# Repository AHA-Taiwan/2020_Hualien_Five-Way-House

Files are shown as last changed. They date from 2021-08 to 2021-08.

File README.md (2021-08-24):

# 2020｜花蓮壽豐｜誠什商店
## _Five-Way House_, Hualien, Taiwan

>Humanitarian Architecture in Hualien<br/>
>
>以台灣國產木材為主體構築材料之人道建築案例，主要材料來源自：行政院農業委員會林務局「台灣木材」標章與明吉木業「台灣杉」。由GROUP B（國立臺南藝術⼤學建築藝術研究所場域。結構。⾏動組）發展設計，與大花蓮縣鄉村社區⼤學發展協會、五味屋學童及國立臺南藝術⼤學建築藝術研究所學校單位合作進行實作。<br/>

從豐⽥⾞站出發，沿途觀察豐裡社區、五味屋及其位於各地的據點，最後回到五味屋裡的孩⼦，都是值得被細細閱讀的⼈⽂與歷史。期望藉由此項計畫，結合在地美感教育，使來訪的⼈們了解豐裡社區，關懷在地⽂化。以「誠什商店」為起點，整合村⼦特⾊以及在地孩⼦們的⽇常⼯作樣貌，串聯整個豐裡社區：透過孩⼦與村⺠們的實際參與，制定專屬課程，從修繕到維護，從中學習結構美學、建立⽣活美感，進⼀步培養⾃⼒造屋的能⼒，也喚起對這塊⼟地的歸屬感，塑造豐裡社區獨特⽣活模樣。<br/>

## 基地環境：<br/>
台灣東南地區，北回歸線以南，有焚風、颱風、東北季風，海風具高度鹽分，設計時需注意材料防潮防蝕保護。<br/>
* 基地環境氣象資料：https://www.cwb.gov.tw/V8/C/W/Town/Town.html?TID=1001506 <br/>
* 氣象觀測歷史紀錄：<br/>
https://e-service.cwb.gov.tw/HistoryDataQuery/DayDataController.do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<br/>

* 花蓮縣縣氣候月平均氣溫、月平均降雨量、風速與相對濕度數據圖表<br/>
 （取自交通部中央氣象局，統計期間為 1991-2020 年）<br/>



* Google Map 位置：https://goo.gl/maps/mkiesZs2zZFcKfTb6<br/>


***
## 專案介紹：<br/>

* 主要建材：台灣杉 [ 15 x 32 x 120 cm ] 尺寸。
* 數位模型［ 整體木構 3D ］：

室內木構 Interior Post and Beam/Wooden Structures<br/>
Digital Model Link: https://skfb.ly/opw7H 與 https://skfb.ly/opw7W
<br/>
<br/>
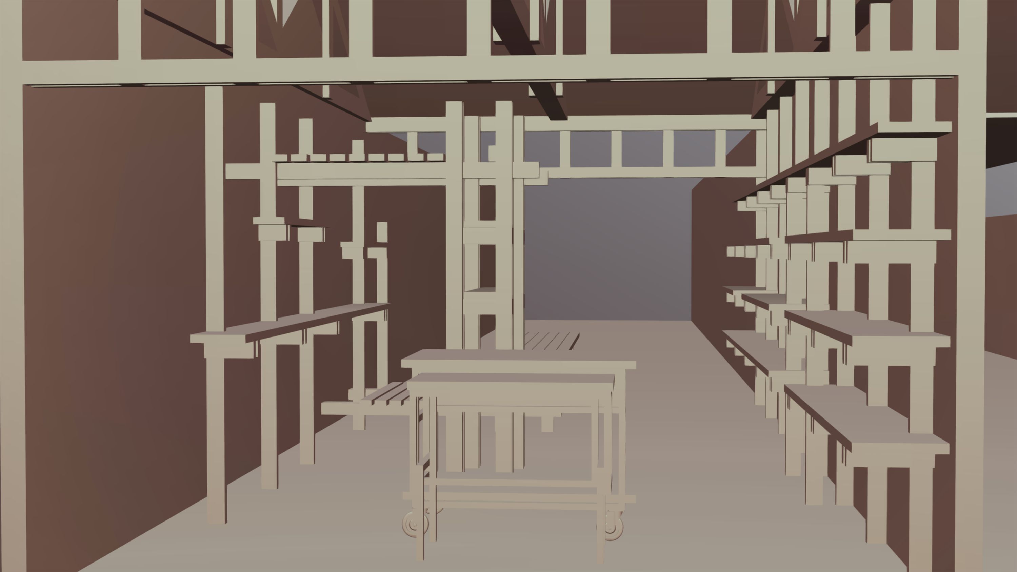
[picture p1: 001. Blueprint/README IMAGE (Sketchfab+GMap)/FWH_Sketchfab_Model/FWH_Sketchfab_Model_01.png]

<br/>
<br/>
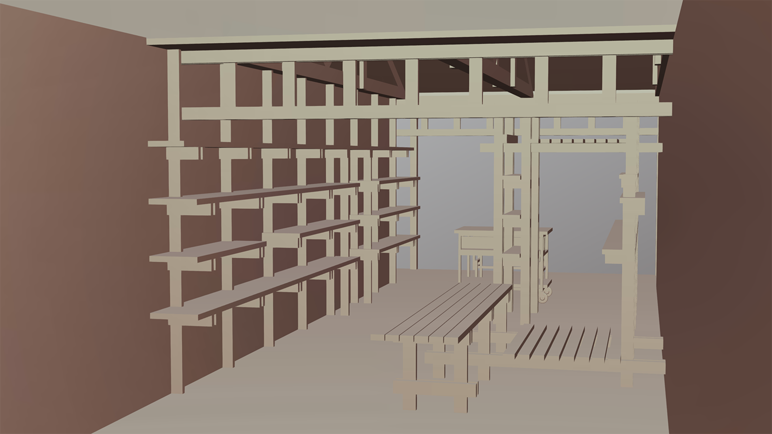
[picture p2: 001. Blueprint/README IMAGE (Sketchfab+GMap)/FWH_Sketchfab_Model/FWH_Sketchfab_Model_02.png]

<br/>
<br/>
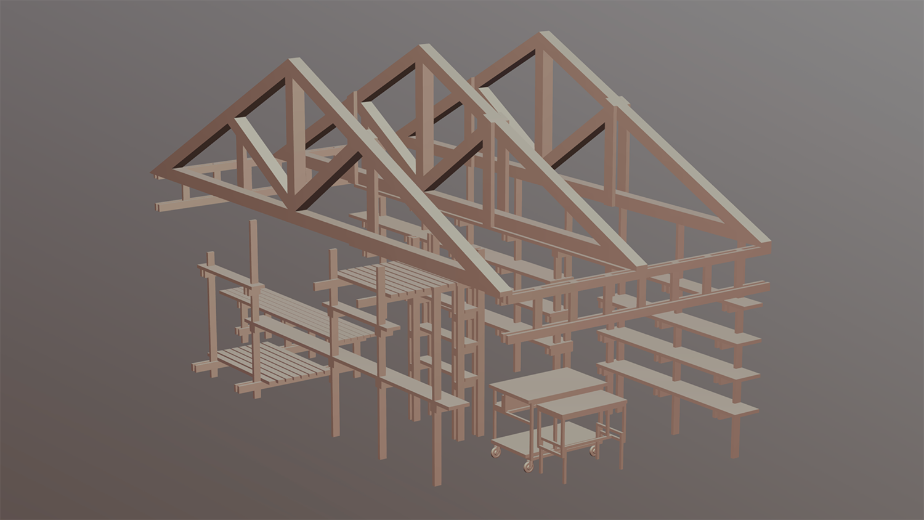
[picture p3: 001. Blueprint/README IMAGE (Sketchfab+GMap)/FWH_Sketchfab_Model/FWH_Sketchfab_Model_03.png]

<br/>
<br/>
推車木桌 Desk Trolley<br/>
Digital Model Link: https://skfb.ly/opwqn
<br/>
<br/>
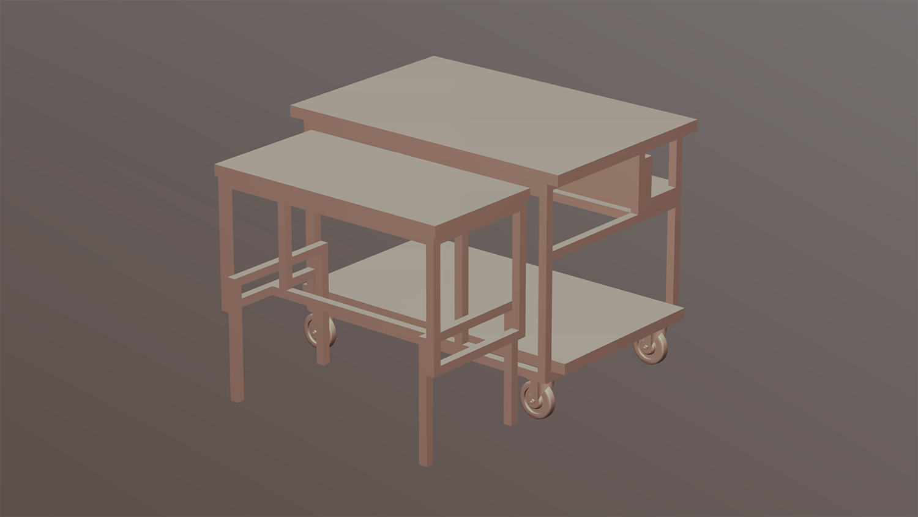
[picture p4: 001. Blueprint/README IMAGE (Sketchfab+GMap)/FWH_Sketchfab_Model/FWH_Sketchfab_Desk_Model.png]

<br/>
<br/>
***
## 如何達成合作建造：<br/>
* 請參閱［初次合作建造就上手 Collab-Const-Quick-Guide］：<br/>
https://github.com/AHA-Taiwan/Collab-Const-Quick-Guide/wiki <br/>
***
## 確保工作安全：<br/>
* 請參閱［合作建造-安全規範 Collab-Const-Safety］：<br/>
https://github.com/AHA-Taiwan/Collab-Const-Safety/wiki <br/>
***
## 探索合作資源：<br/>
* 請參閱［合作建造-資源探索 Collab-Const-Source］：<br/>
https://github.com/AHA-Taiwan/Collab-Const-Source/wiki <br/>
***
## 取得建造知識：<br/>
* 關於一般的常用構造技術（Techniques），請參閱［合作建造-學習知識 Collab-Const-Learning］：<br/>
https://github.com/AHA-Taiwan/Collab-Const-Learning/wiki <br/>
* 關於本案的特殊構築技術（Tectonic）， 請參閱［本案資料夾 002. Handbook］：<br/>
https://github.com/AHA-Taiwan/2020_Hualien_Five-Way-House/tree/main/002.%20Handbook<br/>
***

> #### 歡迎參與專案開發，Branch合併可向專案管理者提出請求

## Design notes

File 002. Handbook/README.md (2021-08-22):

Constr-Process Sheet (.doc+pdf)--工項工序表<br/>

Construction Method (photos)--施工工法, Link: https://drive.google.com/drive/u/4/folders/16N8T6Yqsu6y0wHSA50tWvrSBKL6h-Asd

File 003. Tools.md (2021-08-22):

# 工具清單與故障維修紀錄 
主要紀錄整體施工過程中，所有使用之工具名稱、規格、數量、單位、廠牌、工具來源、維修紀錄(日期)等，從中可間接推估工具數量及機具購買或租借成本。

## 安全工具 
|編碼|工具名稱|規格|數量|單位|廠牌|工具來源|維修紀錄|
|:-:|:-:|:-:|:-:|:-:|:-:|:-:|:-:|
|SS001|安全帽|工地用|6|頂|一般|AHA TL|無|
|SS002|安全繩|跳傘式|2|條|一般|AHA TL|無|
|SS003|安全繩|腰繫式|4|條|一般|AHA TL|無|
|SS004|護目罩|一般|6|副|一般|AHA TL|無|
|SS005|口罩|一般|1|盒|一般|AHA TL|無|
|SS006|手套|一般|4|打|一般|AHA TL|無|
|SS007|蚊帳|一般|4|頂|一般|AHA TL|無|
|SS008|工作板|一般|2|片|一般|AHATL|無|
***
## 手工具 
|編碼|工具名稱|規格|數量|單位|廠牌|工具來源|維修紀錄|
|:-:|:-:|:-:|:-:|:-:|:-:|:-:|:-:|
|HT001|捲尺|5.5m)|6|個|一般|AHA TL|無|
|HT002|大直角尺|一般|4|把|一般|AHA TL|無|
|HT003|小直角尺|一般|4|把|一般|AHA TL|無|
|HT004|大夾具|F夾|4|把|一般|AHA TL|無|
|HT005|小夾具|F夾|4|把|一般|AHA TL|無|
|HT006|老虎鉗|一般|5|把|一般|AHA TL|無|
|HT007|尖嘴鉗|一般|5|把|一般|AHA TL|無|
|HT008|螺絲起子|一般|5|把|一般|AHA TL|無|
|HT009|老鼠尾|一般|5|把|一般|AHA TL|無|
|HT010|大鐵鎚|一般|1|支|一般|AHA TL|無|
|HT011|鐵鎚|一般|6|支|一般|AHA TL|無|
|HT012|鐵鎚|一般|6|支|一般|AHA TL|無|
|HT013|板手|一般|10|支|一般|AHA TL|無|

***
## 電動工具 
|編碼|工具名稱|規格|數量|單位|廠牌|工具來源|維修紀錄|
|:-:|:-:|:-:|:-:|:-:|:-:|:-:|:-:|
|PT001|手持線鋸機|一般|2|台|一般|AHA TL|無|
|PT002|砂輪機|一般|2|台|一般|AHA TL|無|
|PT003|插電式電鑽|一般|4|支|一般|AHA TL|無|
|PT004|角度鋸|一般|1|台|一般|AHA TL|無|
|PT005|直立式鑽床|一般|1|台|一般|AHA TL|無|
***
## 氣動工具 
|編碼|工具名稱|規格|數量|單位|廠牌|工具來源|維修紀錄|
|:-:|:-:|:-:|:-:|:-:|:-:|:-:|:-:|
|AT001|空壓機|一般|1|台|士東|AHA TL|無|
|AT002|空壓機管|一般|1|條|士東|AHA TL|無|
|AT003|氣動拋光機|RC5|2|台|士東|AHA TL|無|
|AT004|轉接頭|三叉|1|個|一般|AHA TL|無|
|AT005|空氣噴槍|一般|1|支|一般|AHA TL|無|
***
## 輔助工具 
|編碼|工具名稱|規格|數量|單位|廠牌|工具來源|維修紀錄|
|:-:|:-:|:-:|:-:|:-:|:-:|:-:|:-:|
|FS001|動力延長線|100M|3|條|一般|AHA TL|無|
|FS002|輪座延長線|100M|1|座|一般|AHA TL|無|
|FS003|鹵素地燈|一般|2|座|一般|AHA TL|無|
|FS004|鹵素地燈管|一般|14|條|一般|AHA TL|無|
|FS005|LED 地燈|一般|3|座|一般|AHA TL|無|
|FS006|工作燈|一般|6|座|一般|AHA TL|無|
|FS007|工作燈泡|一般|10|顆|一般|AHA TL|無|
|FS008|頭燈|一般|2|條|一般|AHA TL|無|
|FS009|工作梯|一般|2|組|一般|AHA TL|無|
|FS010|腳架|一般|1|支|一般|AHA TL|無|
|FS011|籃子|一般|4|台|一般|AHA TL|無|
|FS012|墨綠色工作袋|一般|2|袋|一般|AHA TL|無|
***
## 耗材工具 
|編碼|工具名稱|規格|數量|單位|廠牌|工具來源|維修紀錄|
|:-:|:-:|:-:|:-:|:-:|:-:|:-:|:-:|
|TC001|墨斗+墨汁|無|1|組|一般|AHA TL|無|
|TC002|油漆刷|無|10|把|一般|AHA TL|無|
|TC003|鉛筆|無|10|支|一般|AHA TL|無|
|TC004|麥克筆|無|5|支|一般|AHA TL|無|
|TC005|圓形砂紙|一般|2|盒|一般|AHA TL|無|
|TC006|砂紙|#150|1|盒|一般|AHA TL|無|
|TC007|砂紙|#240|1|盒|一般|AHA TL|無|
|TC008|水線|一般|1|捆|一般|AHA TL|無|
|TC009|鋼釘|一般|1|盒|一般|AHA TL|無|
|TC010|切砂輪片|一般|10|片|一般|AHA TL|無|
|TC011|磨砂輪片|一般|5|片|一般|AHA TL|無|
|TC012|線鋸片紙盒|一般|1|盒|一般|AHA TL|無|
|TC013|長鑽頭|15mm|1|支|一般|AHA TL|無|
|TC014|長鑽頭|8mm|4|支|一般|AHA TL|無|
|TC015|鑽頭組白盒|一般|2|盒|一般|AHA TL|無|
|TC016|鑽頭組紙盒|一般|1|盒|一般|AHA TL|無|

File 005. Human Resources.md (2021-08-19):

# 專業者佈局與人力成本紀錄 
主要紀錄整體施工過程中，專業者、準專業者、非專業者於不同工項所花費時數，從中可間接推估建造施工人力經費及時間成本。
專業者M、準專業者P、非專業者N，當地人加註C

***
## 室內木構與推車木桌
|人力編碼|當地人|工作總時數(hrs)|請工|換工|志工|
|:-:|:-:|:-:|:-:|:-:|:-:|
|M01 | |80 | | |V |
|P01 | |80 | | |V |
|P02 | |80 | | |V |
|P03 | |80 | | |V |
|P04 | |80 | | |V |
|P05 | |80 | | |V |
|N01 | |80 | | |V |
|N02 | |80 | | |V |
|N03 | |80 | | |V |
|N04 | |80 | | |V |
|N05 | |80 | | |V |
|N06 | |80 | | |V |
|N07 | |80 | | |V |
|N08 | |80 | | |V |
|N09 | |80 | | |V |
***

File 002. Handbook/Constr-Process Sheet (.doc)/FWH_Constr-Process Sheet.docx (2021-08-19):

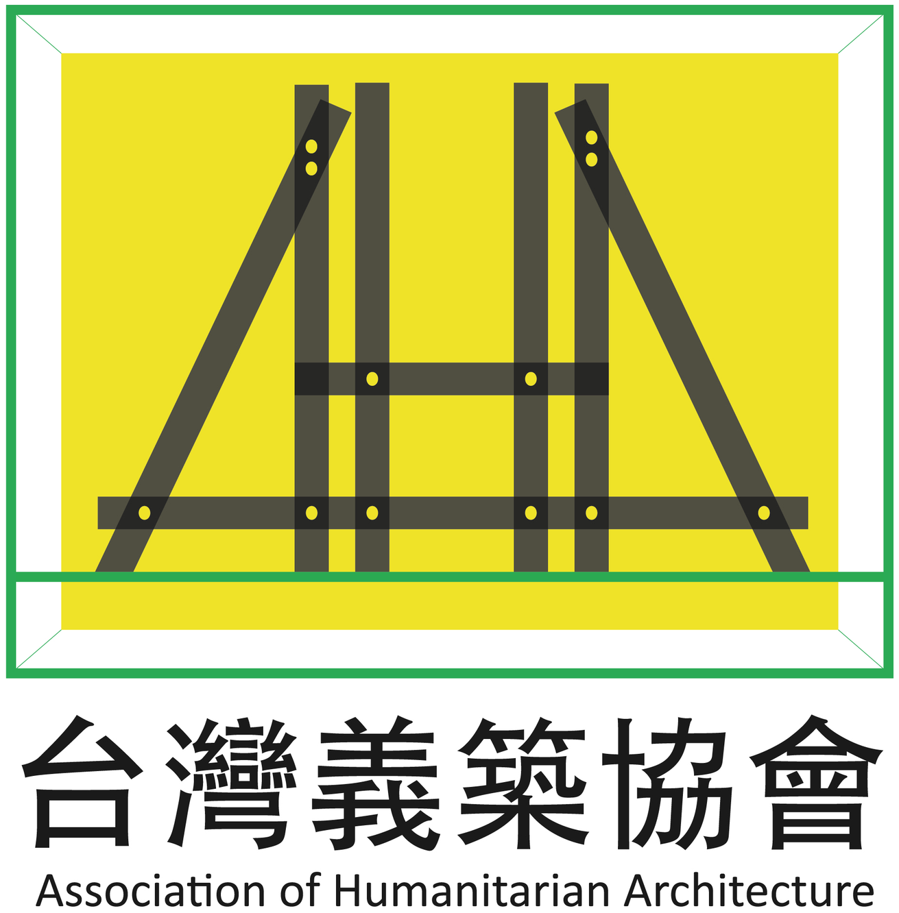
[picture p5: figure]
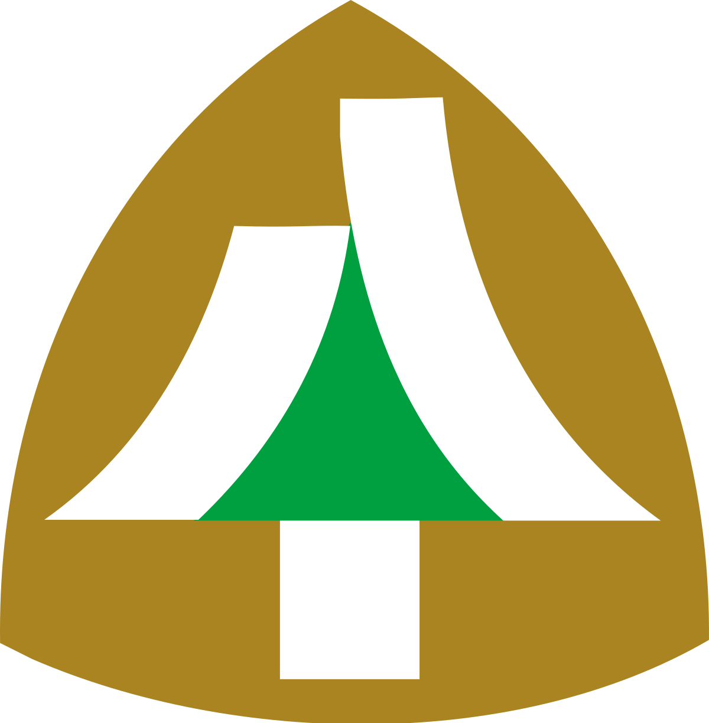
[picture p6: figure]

2020年 花蓮五味屋 誠什商店&誠什車 義築作品

生產製程文件

作業一、整理基地環境 | | 項次 | 作業順序 | | 備註

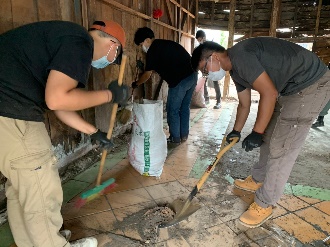
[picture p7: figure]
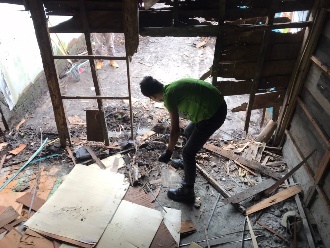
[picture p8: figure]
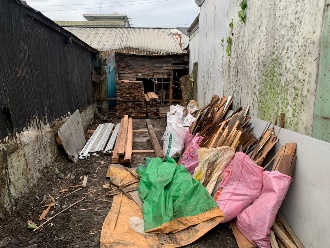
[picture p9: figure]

項次1 項次1 | 項次1 項次2、3 | 1 | 清理與整理基地環境
| | 2 | 搬運木料至基地後方空出工作區
| | 3 | 清點木料數量
| | 項次 | 原料 | 設備 | 站別
| | a | 無 | 掃帚、畚斗、圓鍬 | 木料區、裁切區、鐵工區、組裝區
| | b | 斷面3.8*8.9cm木料 | 帆布 | 木料區
| | C | 斷面3.8*8.9cm木料 | 無 | 木料區

作業二、誠什商店及誠什車打樣 | | 項次 | 作業順序 | | 備註

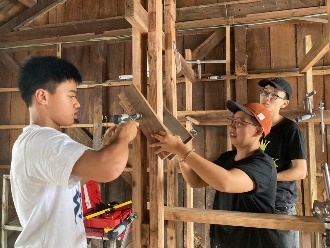
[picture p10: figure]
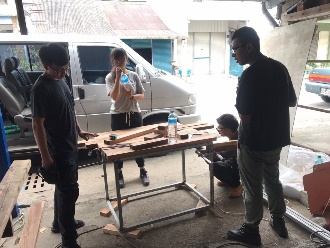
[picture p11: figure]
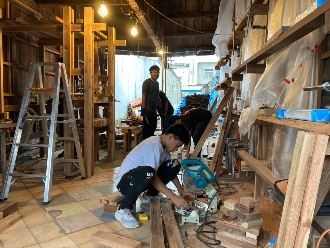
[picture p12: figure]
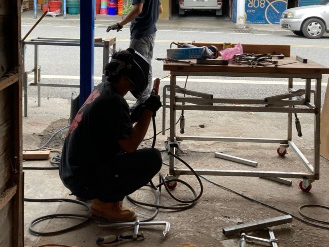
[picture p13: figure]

項次1 項次3 項次4、5 | 項次2 項次3 項次6 | 1 | 木材切割尺寸測量標註
| | 2 | 木材裁切
| | 3 | 誠什商店內部打樣
| | 4 | 方管切割尺寸測量標註
| | 5 | 方管裁切
| | 6 | 焊接誠什車架構
| | 項次 | 原料 | 設備 | 站別
| | a | 斷面3.8*8.9cm木料 | 捲尺、奇異筆、角尺 | 裁切區
| | b | 斷面3.8*8.9cm木料 | 斬斷機 | 裁切區
| | c | 已裁切之木料 | 水平尺、夾具 | 組裝區
| | d | 斷面3*3cm方管 | 捲尺、奇異筆、角尺 | 鐵工區
| | e | 斷面3*3cm方管 | 斬斷機、砂輪機 | 鐵工區
| | f | 已裁切之方管 | 電銲機 | 鐵工區

作業三、座椅設計、打樣與組裝 | | 項次 | 作業順序 | | 備註

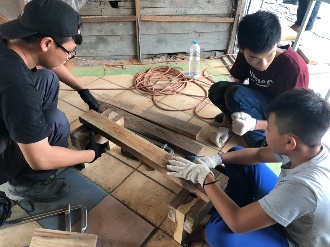
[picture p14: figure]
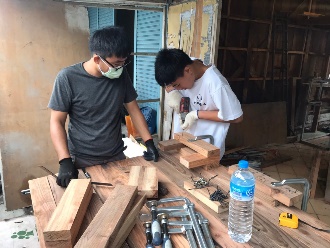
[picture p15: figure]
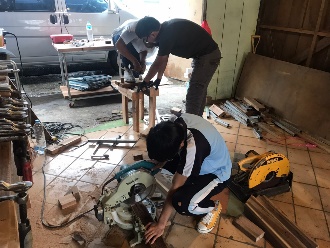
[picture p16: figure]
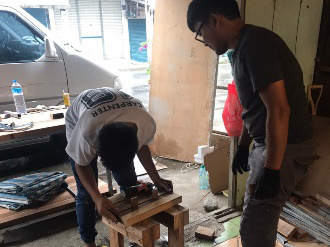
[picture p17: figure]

項次1 項次2 項次4 | 項次2 項次3 項次4 | 1 | 座椅尺寸設計與討論
| | 2 | 座椅打樣
| | 3 | 裁切木料
| | 4 | 座椅組裝
| | 項次 | 原料 | 設備 | 站別
| | a | 已裁切之木料 | 捲尺、筆、角尺、夾具 | 組裝區
| | b | 已裁切之木料 | 捲尺、筆、角尺、夾具 | 組裝區
| | c | 斷面3.8*8.9cm木料 | 捲尺、筆、角尺、斬斷機 | 裁切區
| | d | 已裁切之木料、螺絲 | 起子機、夾具、捲尺、角尺 | 組裝區

作業四、誠什商店家具設計、組裝 | | 項次 | 作業順序 | | 備註

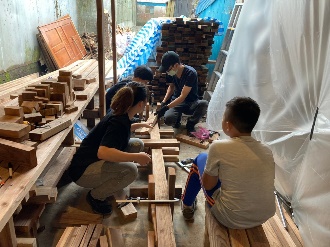
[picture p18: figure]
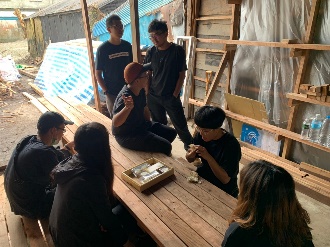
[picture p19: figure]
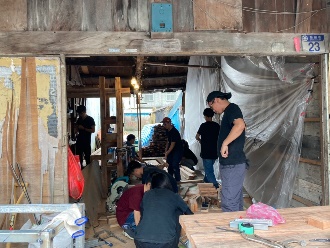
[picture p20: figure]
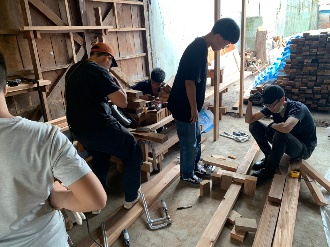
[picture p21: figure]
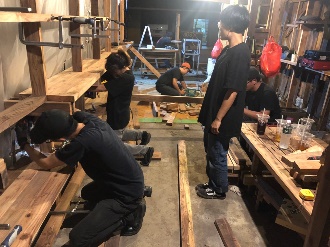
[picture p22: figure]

項次1 項次2 項次4 | 項次2 項次3 項次4 | 1 | 家具尺寸設計與討論
| | 2 | 家具打樣
| | 3 | 裁切木料
| | 4 | 家具組裝
| | 項次 | 原料 | 設備 | 站別
| | a | 已裁切之木料 | 捲尺、筆、角尺、夾具 | 組裝區
| | b | 已裁切之木料 | 捲尺、筆、角尺、夾具 | 組裝區
| | c | 斷面3.8*8.9cm木料 | 捲尺、筆、角尺、斬斷機 | 裁切區
| | d | 已裁切之木料、螺絲 | 起子機、夾具、捲尺、角尺 | 組裝區

作業名稱：五、誠什車設計、組裝 | | 項次 | 作業順序 | | 備註

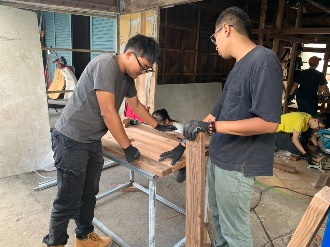
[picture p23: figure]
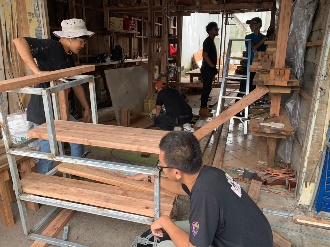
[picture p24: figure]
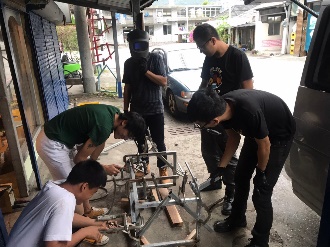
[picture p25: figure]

項次1 項次2 項次4 | 項次2 項次4 | 1 | 誠什車設計與討論
| | 2 | 誠什車打樣
| | 3 | 裁切木料
| | 4 | 誠什車組裝
| | 項次 | 原料 | 設備 | 站別
| | a | 已裁切之木料 | 捲尺、筆、角尺、夾具 | 組裝區
| | b | 已裁切之木料 | 捲尺、筆、角尺、夾具 | 組裝區
| | c | 斷面3.8*8.9cm木料 | 捲尺、筆、角尺、斬斷機 | 裁切區
| | d | 已裁切之木料、螺絲 | 起子機、夾具、捲尺、角尺 | 組裝區

作業六、家具收邊與整體收尾 | | 項次 | 作業順序 | | 備註

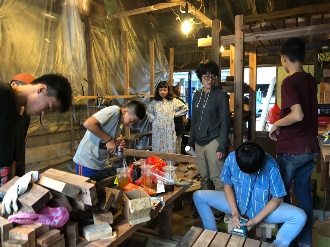
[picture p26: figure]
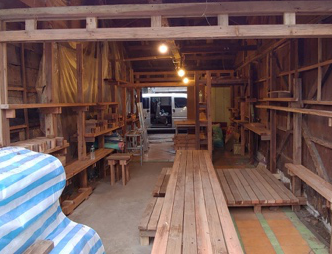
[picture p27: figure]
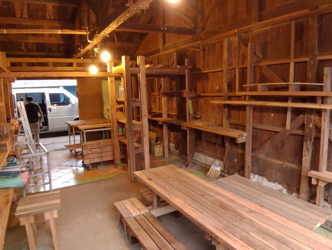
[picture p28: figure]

項次1 項次2 | 項次1 項次2 | 1 | 家具邊角收編
| | 2 | 整體階段完工
| | 項次 | 原料 | 設備 | 站別
| | a | 無 | 偏心砂磨機、砂紙 | 組裝區

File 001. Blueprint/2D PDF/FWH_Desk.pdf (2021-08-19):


⼩推⾞立⾯說明

原型-
⼩桌⼦收納至拖⾞內

變化01-
⼩桌⼦拿出來可以當椅⼦使⽤

變化02-
⼩桌⼦⾼度可調整，可變成桌⼦

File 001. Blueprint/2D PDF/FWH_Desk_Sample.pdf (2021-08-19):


推車小桌子

小桌子的升降路徑由兩片固定件固定，
讓桌子能保持垂直升降

調整至適當高度後，由螺栓固定

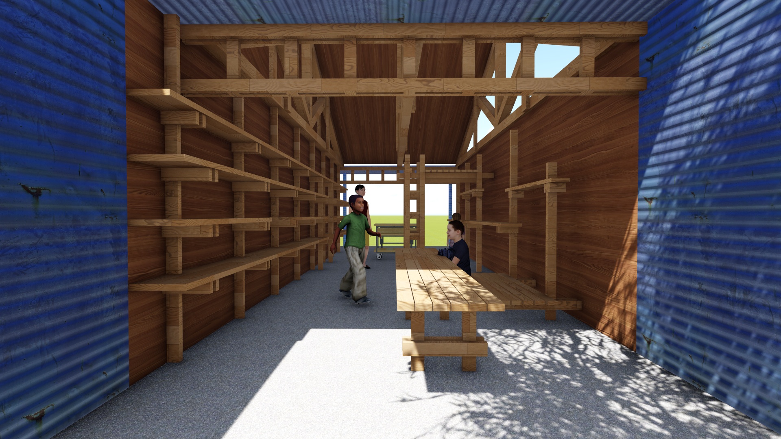
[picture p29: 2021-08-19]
001. Blueprint/3D Pictures/FWH_Rendered Model_02.jpg

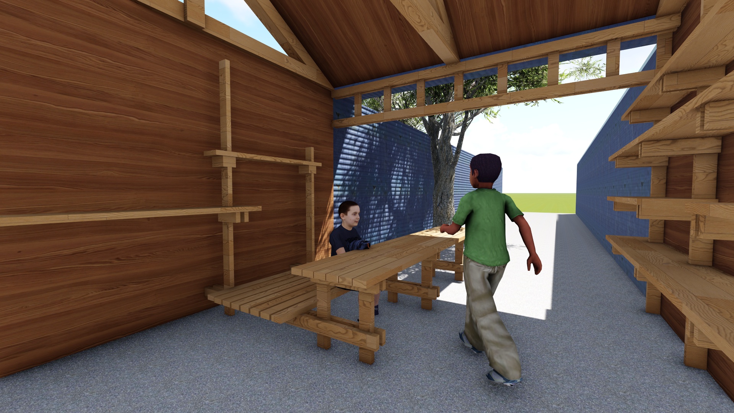
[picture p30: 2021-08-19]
001. Blueprint/3D Pictures/FWH_Rendered Model_01.jpg

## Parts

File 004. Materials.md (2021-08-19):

# 材料清單與部件編碼紀錄 
主要紀錄整體施工過程中，各部位構件之材料名稱、規格、數量、單價、材料來源、廠商資訊等，從中可推估材料經費及運輸成本。

## 主要建材
|編碼|材料名稱|部件位置|規格|需要數量|實購數量|材料來源|
|:-:|:-:|:-:|:-:|:-:|:-:|:-:|
|S001|台灣杉|室內木構與推車木桌|15 x 32 x 120 cm|360|360|[正昌製材](http://www.wood.jen.com.tw/fengxi/front/bin/home.phtml)|
***

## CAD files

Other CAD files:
001. Blueprint/3D Model (.skp)/FWH_Model.skp

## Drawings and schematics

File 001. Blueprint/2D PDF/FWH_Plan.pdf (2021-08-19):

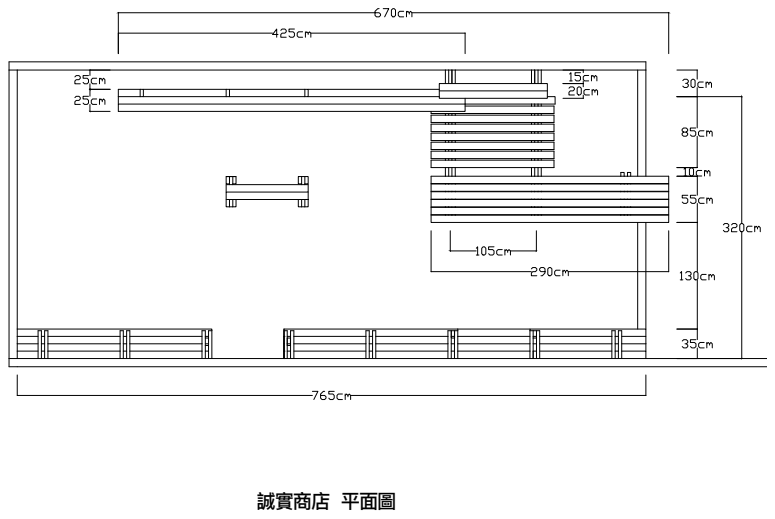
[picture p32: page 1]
誠實商店 平⾯圖

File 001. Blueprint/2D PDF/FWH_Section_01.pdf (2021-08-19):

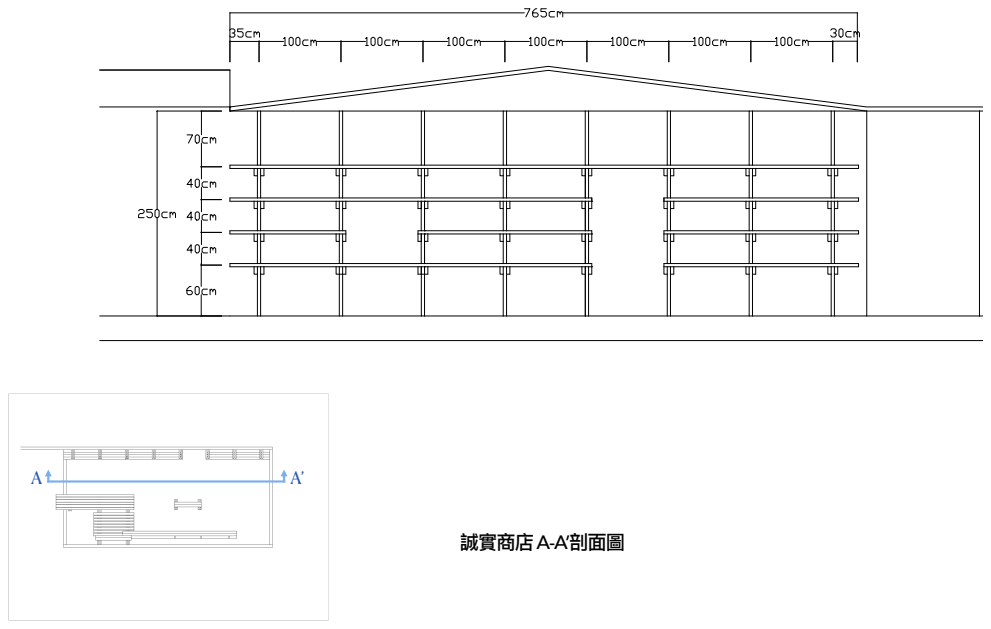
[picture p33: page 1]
誠實商店 A-A’剖⾯圖

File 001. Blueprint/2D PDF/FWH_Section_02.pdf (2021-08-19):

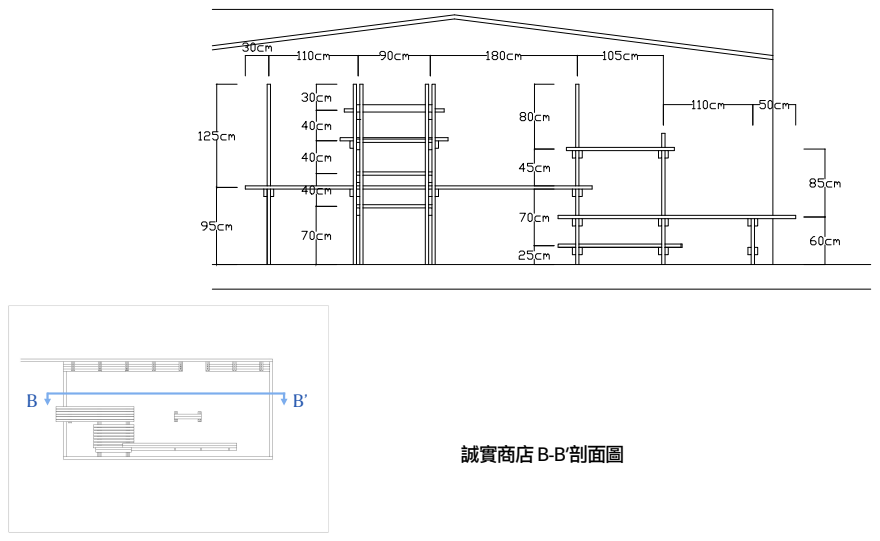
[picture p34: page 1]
誠實商店 B-B’剖⾯圖

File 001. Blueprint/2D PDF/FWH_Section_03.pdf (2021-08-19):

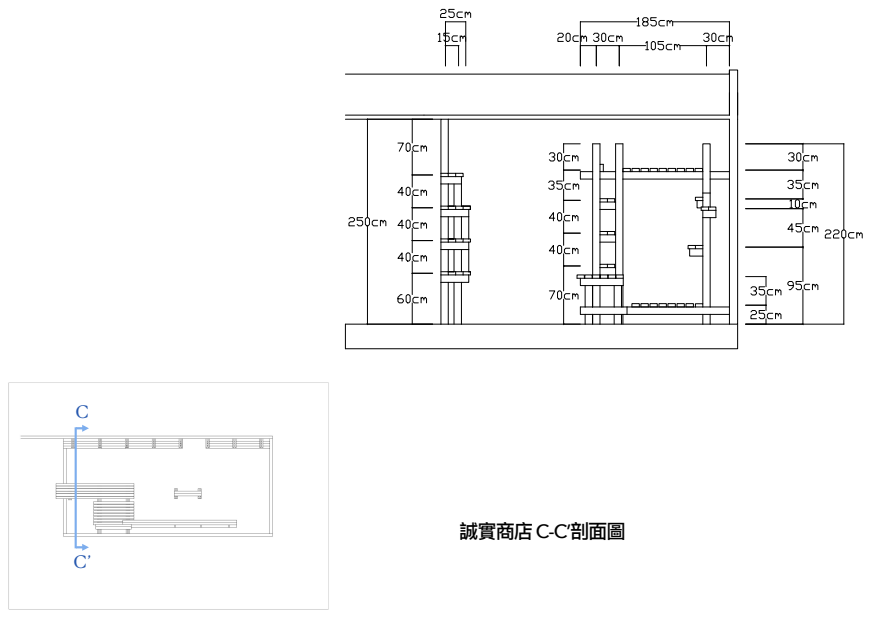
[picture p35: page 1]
誠實商店 C-C’剖⾯圖

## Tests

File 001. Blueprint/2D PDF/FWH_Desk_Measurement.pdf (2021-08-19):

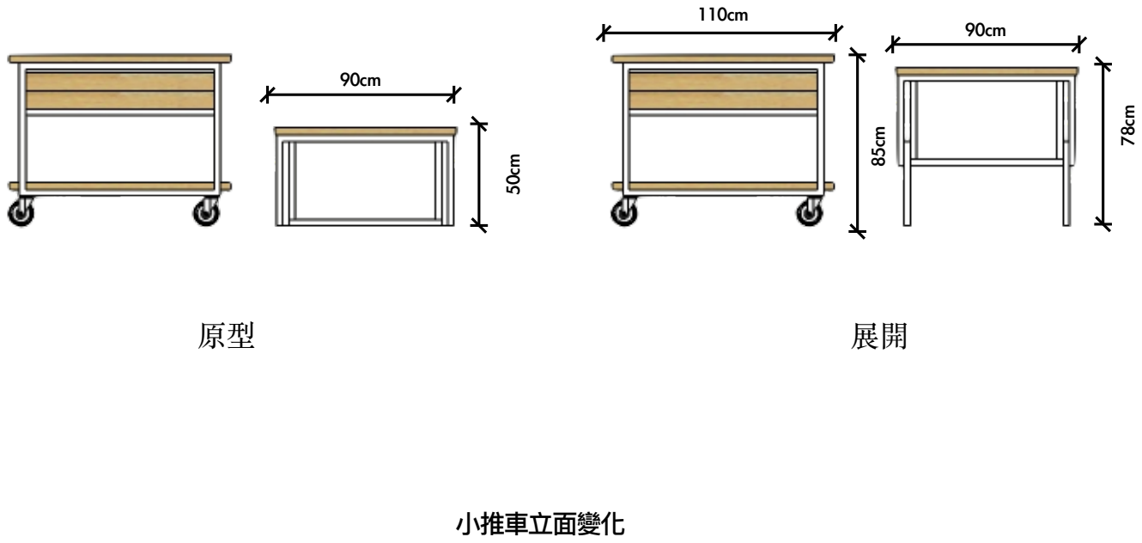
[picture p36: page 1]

## ⼩推⾞立⾯變化

原型 | 展開

110cm

85cm

78cm

50cm

90cm

90cm
